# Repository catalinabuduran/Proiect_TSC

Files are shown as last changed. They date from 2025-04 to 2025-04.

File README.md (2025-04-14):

# OpenBook - Open Source e-Book Reader

## Functionalitate hardware

Dispozitivul OpenBook integreaza o serie de module si componente menite sa ofere o experienta completa pentru citirea cartilor in format digital, precum si extinderea functiilor prin senzori si periferice externe. Hardware-ul este compus din mai multe blocuri functionale, fiecare avand rolul. Am integrat atat componente de interfata (buton, ecran), cat si senzori, circuite de alimentare si protectie.

### Componente principale:

## Dispozitivul este compus dintr-un set de componente atent alese pentru a oferi un echilibru perfect intre performanta, consum redus de energie si modularitate. ##
|  Componenta | Descriere |
|---|---|
|ESP32-C6-WROOM-1-N8  | MCU principal cu WiFi 6, BLE 5.0, SPI, I2C, UART |
|E-paper Display | Afisaj ultra-low power, interfata SPI |
|SD Card | Stocare pentru fisiere e-book si configurari |
|NOR Flash 64MB  | Memorie suplimentara pentru firmware si date |
|RTC-DS3231SN | Ceas in timp real, exact si stabil |
| BME688 | Senzor de mediu complet: T, RH, presiune, VOC |
| MAX17048 | Masurare SoC baterie, tensiune, temperatura |
|MCP73831 | Incarcare LiPo simpla si eficienta |
|XC6220 LDO | Regulare 5V -> 3.3V cu zgomot scazut |
|USB-C | Alimentare + flash firmware + protectie ESD |
|Qwiic/Stemma QT | Extensie rapida pentru senzori I2C |

---

## Pinout ESP32-C6

Mai jos este un rezumat al pinilor folositi pe microcontroller, cu functiile si componenta asociata:

| GPIO  | Componenta | Functie |
|---|---|---|
| EN | Buton Reset | Reset hardware |
| IO0 | RTC | INT_RTC (interupt RTC) |
| IO1 | RTC | 32KHz output |
| IO2 | SD Card | MISO |
| IO3 | E-paper Display | EPD_BUSY |
| IO4 | SD Card | SS_SD (chip select) |
| IO5 | E-paper Display | EPD_DC |
| IO6 | SPI Shared | SCK |
| IO7 | SPI Shared | MOSI |
| IO8 | GPIO | Utilizare generica |
| IO9 | Boot Button | Mod programare |
| IO10 | E-paper Display | EPD_CS |
| IO11 | NOR Flash | FLASH_CS |
| IO12 | USB Interface | USB_D- |
| IO13 | USB Interface | USB_D+ |
| IO15 | Buton Change | Detectare schimbare |
| IO16 | UART | TX (debug serial) |
| IO17 | UART | RX (debug serial) |
| IO18 | RTC | RTC_RST |
| IO19 | MAX17048 | I2C_PW (alimentare I2C) |
| IO20 | E-paper Display | EPD_3V3_C (power control) |
| IO21 | I2C Shared | SDA |
| IO22 | I2C Shared | SCL |
| IO23 | E-paper Display | EPD_RST |

---

## Arhitectura si comunicatii

- **SPI Bus** este partajat intre: SD Card, E-paper Display, NOR Flash
- **I2C Bus** este partajat intre: RTC, BME688, MAX17048, Qwiic port
- **UART** este utilizat pentru debugging (TX/RX)
- **USB-C** foloseste GPIO dedicate pentru DP/DM si incarcare

---
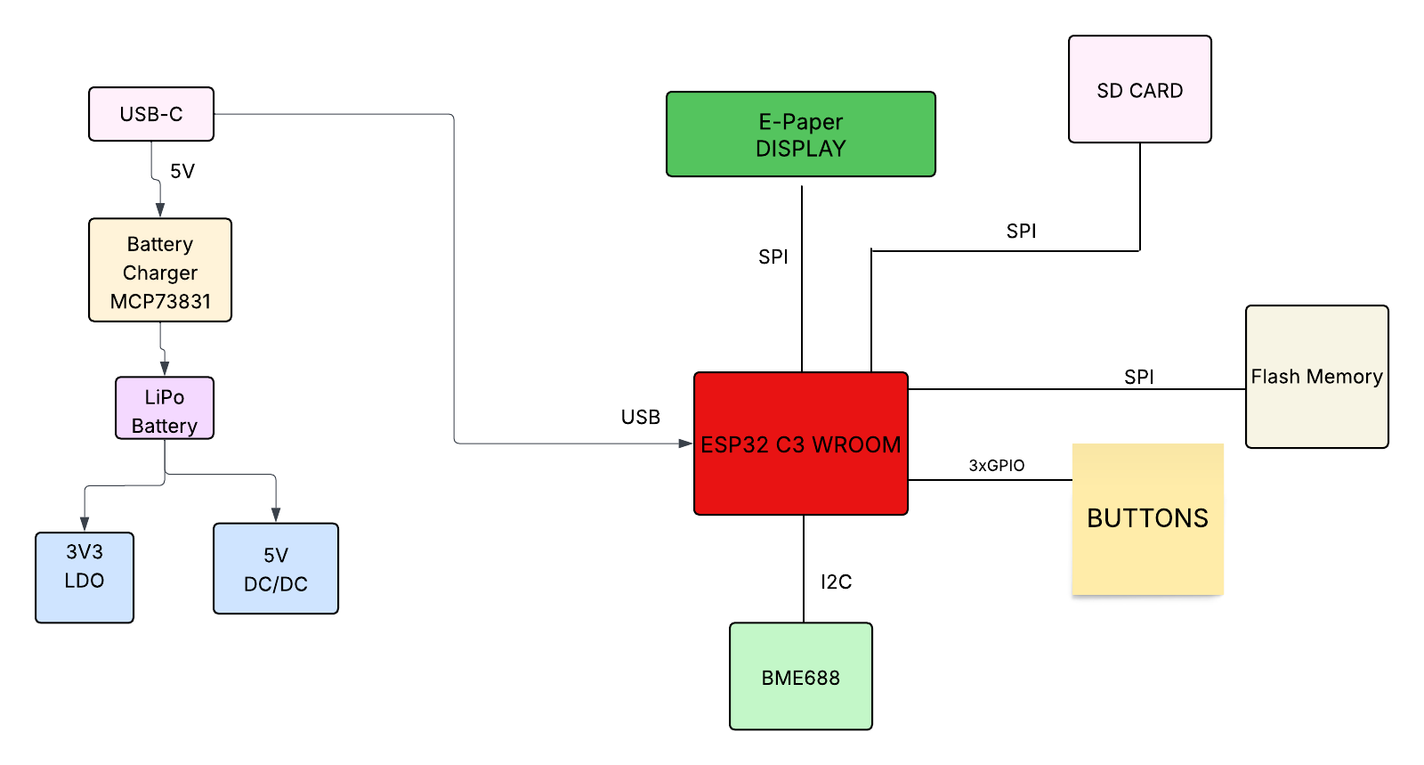
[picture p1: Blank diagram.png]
Diagrama BLOC


# BOM TSC - Lista de componente

| Nr. piesa | Nume piesa | Site | Datasheet |
| --- | --- | --- | --- |
| 1 | BOOT_BUTON | https://www.snapeda.com/parts/EVQP7L01P/Panasonic%20Electronic%20Components/view-part/?welcome=home | https://www.snapeda.com/parts/EVQP7L01P/Panasonic/datasheet/ |
| 2 | C1, C1_BAT, C1_BAT2, C2,C2_BAT,C3,C4,C4_USB, C5, C5_USB, C6, C7, C8, C9,C10 | https://componentsearchengine.com/part-view/CC0402MRX5R5BB106/YAGEO | https://componentsearchengine.com/Datasheets/2/CC0402MRX5R5BB106.pdf |
| 3 | C10_SUPERCAR | https://industry.panasonic.com/global/en/products/control/switch/light-touch/number/evqpuj02k | https://industry.panasonic.com/global/en/downloads?tab=catalog&small_g_cd=203&part_no=EVQPUJ02K |
| 4 | CHANGE_BUTTON | https://www.snapeda.com/parts/EVQP7L01P/Panasonic%20Electronic%20Components/view-part/?welcome=home | https://www.snapeda.com/parts/EVQP7L01P/Panasonic/datasheet/ |
| 5 | C_DELAY | https://componentsearchengine.com/part-view/CC0402MRX5R5BB106/YAGEO | https://componentsearchengine.com/Datasheets/2/CC0402MRX5R5BB106.pdf |
| 6 | D1 | https://www.snapeda.com/parts/USBLC6-2SC6Y/STMicroelectronics/view-part/?ref=eda | https://www.snapeda.com/parts/USBLC6-2SC6Y/STMicroelectronics/view-part/?ref=eda |
| 7 | EPD_C1,EPD_C2, EPD_C3, EPD_C4, EPD_C5,EPD_C6,EPD_C7,EPD_C8,EPD_C9,EPD_C10,EPD_C11,EPD_C12 | https://componentsearchengine.com/part-view/CC0402MRX5R5BB106/YAGEO | https://componentsearchengine.com/Datasheets/2/CC0402MRX5R5BB106.pdf |
| 8 | IC1 | https://componentsearchengine.com/part-view/BD5229G-TR/ROHM%20Semiconductor | https://datasheet.datasheetarchive.com/originals/distributors/Datasheets_SAMA/f2b9741ef86007909f138d561a359946.pdf |
| 9 | IC4 | https://componentsearchengine.com/part-view/XC6220A331MR-G/Torex | https://product.torexsemi.com/system/files/series/xc6220.pdf |
| 10 | J1 | https://componentsearchengine.com/part-view/FH34SRJ-24S-0.5SH(99)/Hirose | https://www.hirose.com/en/product/document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 |
| 11 | J2 | https://componentsearchengine.com/part-view/USB4110-GF-A/GCT%20(GLOBAL%20CONNECTOR%20TECHNOLOGY) | https://gct.co/files/drawings/usb4110.pdf |
| 12 | J3,J4 | https://www.snapeda.com/parts/PRT-14417/SparkFun/view-part/ | https://www.snapeda.com/parts/PRT-14417/SparkFun%20Electronics/datasheet/ |
| 13 | MCP73831 | https://ro.mouser.com/ProductDetail/Microchip-Technology/MCP73831T-2ACI-OT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 | https://ro.mouser.com/datasheet/2/268/MCP73831_Family_Data_Sheet_DS20001984H-3441711.pdf |
| 14 | L1 | https://ro.mouser.com/ProductDetail/Wurth-Elektronik/744043680?qs=PGXP4M47uW6VkZq%252BkzjrHA%3D%3D | https://www.we-online.com/components/products/datasheet/744043680.pdf |
| 15 | PFMF.050.1 | https://ro.mouser.com/ProductDetail/EPCOS-TDK/B72520T0350K062?qs=dEfas%2FXlABIszF52uu7vrg%3D%3D | https://www.tdk-electronics.tdk.com/inf/75/db/CTVS_14/Surge_protection_series.pdf |
| 16 | Q1,Q2 | https://componentsearchengine.com/part-view/DMG2305UX-7/Diodes%20Incorporated | https://www.diodes.com//assets/Datasheets/DMG2305UX.pdf |
| 17 | Q3 | https://componentsearchengine.com/part-view/SI1308EDL-T1-GE3/Vishay | https://componentsearchengine.com/part-view/SI1308EDL-T1-GE3/Vishay |
| 18 | Rezistente | https://componentsearchengine.com/part-view/R0402%201%25%20100%20K%20(RC0402FR-07100KL)/YAGEO | https://www.yageo.com/upload/media/product/products/datasheet/rchip/PYu-RC_Group_51_RoHS_L_12.pdf |
| 19 | RESET_BUTTON | https://www.snapeda.com/parts/EVQP7L01P/Panasonic%20Electronic%20Components/view-part/?welcome=home | https://www.snapeda.com/parts/EVQP7L01P/Panasonic/datasheet/ |
| 20 | R_BOOT | https://componentsearchengine.com/part-view/R0402%201%25%20100%20K%20(RC0402FR-07100KL)/YAGEO | https://www.yageo.com/upload/media/product/products/datasheet/rchip/PYu-RC_Group_51_RoHS_L_12.pdf |
| 21 | R_CAPACITOR | https://componentsearchengine.com/part-view/R0402%201%25%20100%20K%20(RC0402FR-07100KL)/YAGEO | https://www.yageo.com/upload/media/product/products/datasheet/rchip/PYu-RC_Group_51_RoHS_L_12.pdf |
| 22 | R_CHANGE | https://componentsearchengine.com/part-view/R0402%201%25%20100%20K%20(RC0402FR-07100KL)/YAGEO | https://www.yageo.com/upload/media/product/products/datasheet/rchip/PYu-RC_Group_51_RoHS_L_12.pdf |
| 23 | R_CL1 | https://componentsearchengine.com/part-view/R0402%201%25%20100%20K%20(RC0402FR-07100KL)/YAGEO | https://www.yageo.com/upload/media/product/products/datasheet/rchip/PYu-RC_Group_51_RoHS_L_12.pdf |
| 24 | R_RESET | https://componentsearchengine.com/part-view/R0402%201%25%20100%20K%20(RC0402FR-07100KL)/YAGEO | https://www.yageo.com/upload/media/product/products/datasheet/rchip/PYu-RC_Group_51_RoHS_L_12.pdf |
| 26 | SENSOR2 | https://www.snapeda.com/parts/BME680/Bosch/view-part/?welcome=home | https://www.snapeda.com/parts/BME680/Bosch%20Sensortec/datasheet/ |
| 27 | SJ1 | https://grabcad.com/library/solder-jumpers-1 | https://grabcad.com/library/solder-jumpers-1 |
| 28 | U1 | https://www.snapeda.com/parts/W25Q512JVEIQ/Winbond+Electronics/view-part/?ref=eda | https://www.snapeda.com/parts/W25Q512JVEIQ/Winbond+Electronics/view-part/?ref=eda |
| 29 | U2 | https://www.snapeda.com/parts/ESP32-C6-WROOM-1-N8/Espressif+Systems/view-part/?ref=eda | https://www.snapeda.com/parts/ESP32-C6-WROOM-1-N8/Espressif%20Systems/datasheet/ |
| 30 | U3 | https://www.snapeda.com/parts/DS3231SN%23/Analog+Devices/view-part/?ref=eda | https://www.snapeda.com/parts/DS3231SN%23/Analog%20Devices/datasheet/ |
| 31 | U4 | https://www.snapeda.com/parts/MAX17048G+T10/Analog+Devices/view-part/?ref=eda | https://www.snapeda.com/parts/MAX17048G+T10/Analog%20Devices/datasheet/ |
| 32 | TP-uri | Le-am desenat manual |  |

3D Design
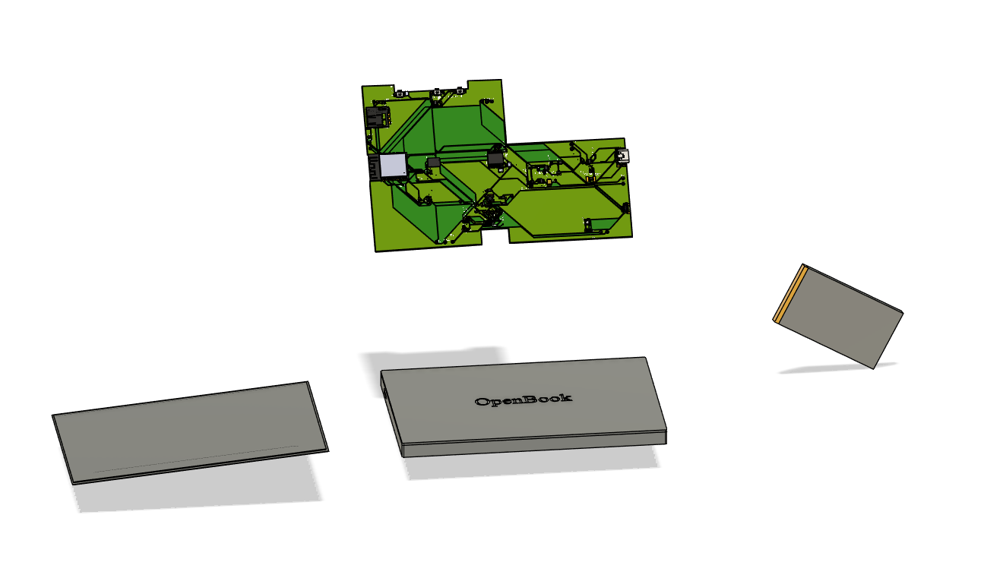
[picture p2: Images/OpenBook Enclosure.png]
OpenBook Enclosure


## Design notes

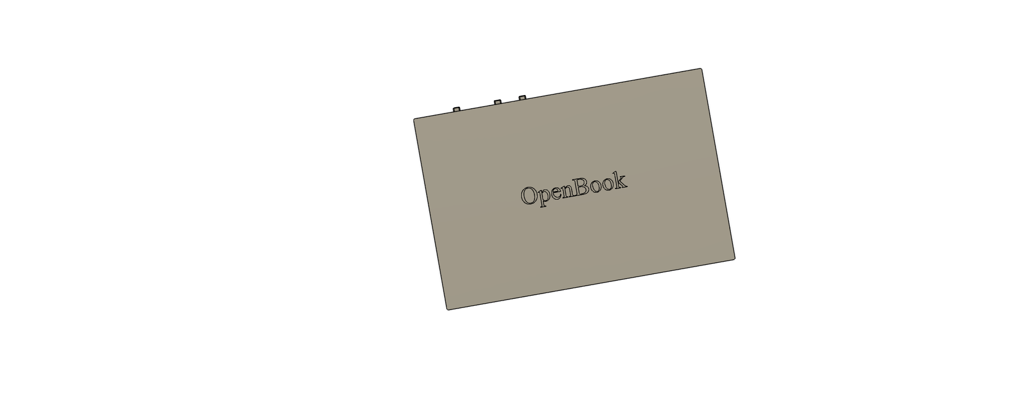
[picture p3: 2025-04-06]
Images/Carcasa.png

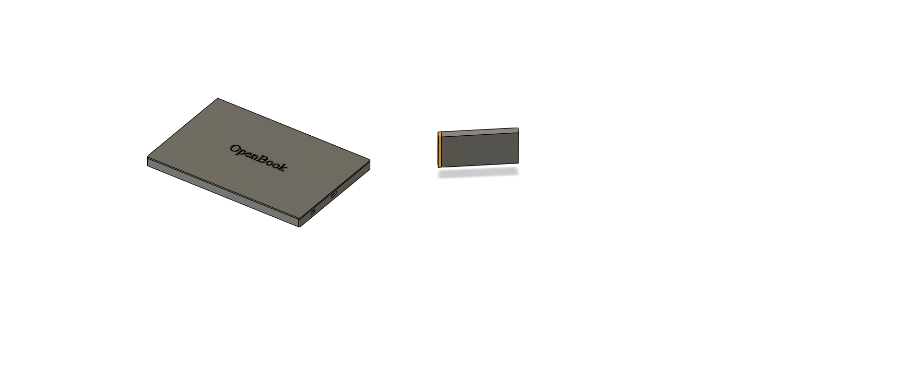
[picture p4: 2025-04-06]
Images/Baterie.png

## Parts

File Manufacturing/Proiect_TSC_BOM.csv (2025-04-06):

Qty | Value | Device | Package | Parts | Description | ARROW_PART_NUMBER | ARROW_PRICE-STOCK | AVAILABILITY | CATEGORY | CENTROID_NOT_SPECIFIED | CHECK_PRICES | COPYRIGHT | DATASHEET | DESCRIPTION | DIGIKEY_DESCRIPTION | DIGIKEY_PART_NUMBER | HEIGHT | LEAD_FREE | MANUFACTURER | MANUFACTURER_NAME | MANUFACTURER_PART_NUMBER | MF | MFR_NAME | MOUSER_PART_NUMBER | MOUSER_PRICE-STOCK | MOUSER_TESTING_PART_NUMBER | MOUSER_TESTING_PRICE-STOCK | MP | MPN | OPERATING_TEMPERATURE | PACKAGE | PACKAGE_SIZE | PACKAGE_TYPE | PART_STATUS | POPULARITY | PREFIX | PRICE | PROD_ID | PURCHASE-URL | ROHS | SERIES | SNAPEDA_LINK | SPICEMODEL | SPICEPREFIX | SUBCATEGORY | TEMPERATURE_COEFFICIENT | TEMPERATURE_RANGE_HIGH | TEMPERATURE_RANGE_LOW | THERMALLOSS | TOLERANCE | TP_SIGNAL_NAME | TYPE | VALUE
1 |  | ADAFRUIT_LEDCHIP-LED0603 | ADAFRUIT_CHIP-LED0603 | CHG_LED | LED
1 |  | ESP32_WROVER_EAGLE-LTSPICE_RR0402 | ESP32_WROVER_EAGLE-LTSPICE_R0402 | R_CAPACITOR | RESISTOR, European symbol |  |  |  |  |  |  |  |  |  |  |  |  |  |  |  |  |  |  |  |  |  |  |  |  |  |  |  |  |  |  |  |  |  |  |  |  |  | NONE | R
1 |  | SJ | SJ | SJ1 | SMD solder JUMPER |  |  |  |  |  |  |  |  |  |  |  |  |  |  |  |  |  |  |  |  |  |  |  |  |  |  |  |  |  | 3
1 | 0.1uF/50V | ESP32_WROVER_EAGLE-LTSPICE_CC0402 | ESP32_WROVER_EAGLE-LTSPICE_C0402 | EPD_C5 | CAPACITOR, European symbol |  |  |  |  |  |  |  |  |  |  |  |  |  |  |  |  |  |  |  |  |  |  |  |  |  |  |  |  |  |  |  |  |  |  |  |  |  | NONE | C
1 | 0.47 | R_CHIP-0402(1005-METRIC) | RESC1005X40 | R3 | Resistor Fixed - Generic |  |  |  | Resistors |  |  |  |  | Chip Resistor 1.05 X 0.54 X 0.40 mm body 0402(1005-METRIC) Package |  |  |  |  |  |  |  |  |  |  |  |  |  |  |  |  |  | 0402 | SMD
1 | 100K | ESP32_WROVER_EAGLE-LTSPICE_RR0402 | ESP32_WROVER_EAGLE-LTSPICE_R0402 | R1_PWRUSB | RESISTOR, European symbol |  |  |  |  |  |  |  |  |  |  |  |  |  |  |  |  |  |  |  |  |  |  |  |  |  |  |  |  |  |  |  |  |  |  |  |  |  | NONE | R
1 | 100K | R_CHIP-0402(1005-METRIC) | RESC1005X40 | R1 | Resistor Fixed - Generic |  |  |  | Resistors |  |  |  |  | Chip Resistor 1.05 X 0.54 X 0.40 mm body 0402(1005-METRIC) Package |  |  |  |  |  |  |  |  |  |  |  |  |  |  |  |  |  | 0402 | SMD
1 | 100k | R_CHIP-0402(1005-METRIC) | RESC1005X40 | R4 | Resistor Fixed - Generic |  |  |  | Resistors |  |  |  |  | Chip Resistor 1.05 X 0.54 X 0.40 mm body 0402(1005-METRIC) Package |  |  |  |  |  |  |  |  |  |  |  |  |  |  |  |  |  | 0402 | SMD
1 | 100nF | EAGLE-LTSPICE_CC0402 | EAGLE-LTSPICE_C0402 | C8 | CAPACITOR, European symbol |  |  |  |  |  |  |  |  |  |  |  |  |  |  |  |  |  |  |  |  |  |  |  |  |  |  |  |  |  |  |  |  |  |  |  |  |  | NONE | C
7 | 100nF | ESP32_WROVER_EAGLE-LTSPICE_CC0402 | ESP32_WROVER_EAGLE-LTSPICE_C0402 | C1, C2, C4_USB, C6, C9, C10, C_DELAY | CAPACITOR, European symbol |  |  |  |  |  |  |  |  |  |  |  |  |  |  |  |  |  |  |  |  |  |  |  |  |  |  |  |  |  |  |  |  |  |  |  |  |  | NONE | C
1 | 100uF TANT | RCL_CPOL-EUCT3528 | RCL_CT3528 | C3 | POLARIZED CAPACITOR, European symbol |  |  |  |  |  |  |  |  |  |  |  |  |  |  |  |  |  |  |  |  |  |  |  |  |  |  |  |  |  | 0 |  |  |  |  |  |  |  |  | C
14 | 10K | ESP32_WROVER_EAGLE-LTSPICE_RR0402 | ESP32_WROVER_EAGLE-LTSPICE_R0402 | R1_PINH, R1_PINH1, R2-PINH, R2-PINH1, R5, R6, R7, R8, R9, R10, R_BOOT, R_CHANGE, R_CL1, R_RESET | RESISTOR, European symbol |  |  |  |  |  |  |  |  |  |  |  |  |  |  |  |  |  |  |  |  |  |  |  |  |  |  |  |  |  |  |  |  |  |  |  |  |  | NONE | R
1 | 10uF | ESP32_WROVER_EAGLE-LTSPICE_CC0402 | ESP32_WROVER_EAGLE-LTSPICE_C0402 | C7 | CAPACITOR, European symbol |  |  |  |  |  |  |  |  |  |  |  |  |  |  |  |  |  |  |  |  |  |  |  |  |  |  |  |  |  |  |  |  |  |  |  |  |  | NONE | C
1 | 112A-TAAR-R03_ATTEND | 112A-TAAR-R03_ATTEND | 112ATAARR03ATTEND | J4 | Micro SD Card Socket, Push-Push Type, Top Mount, SMT, H=1.83mm, 10u |  |  |  |  |  |  |  |  | Micro SD Card Socket | Push-Push Type | Top Mount | SMT | H=1.83mm | 10u |  |  | 1.9mm |  |  | ATTEND | 112A-TAAR-R03 ATTEND
1 | 1uF | EAGLE-LTSPICE_CC0402 | EAGLE-LTSPICE_C0402 | C5 | CAPACITOR, European symbol |  |  |  |  |  |  |  |  |  |  |  |  |  |  |  |  |  |  |  |  |  |  |  |  |  |  |  |  |  |  |  |  |  |  |  |  |  | NONE | C
1 | 1uF/50F | ESP32_WROVER_EAGLE-LTSPICE_CC0402 | ESP32_WROVER_EAGLE-LTSPICE_C0402 | EPD_C12 | CAPACITOR, European symbol |  |  |  |  |  |  |  |  |  |  |  |  |  |  |  |  |  |  |  |  |  |  |  |  |  |  |  |  |  |  |  |  |  |  |  |  |  | NONE | C
8 | 1uF/50V | ESP32_WROVER_EAGLE-LTSPICE_CC0402 | ESP32_WROVER_EAGLE-LTSPICE_C0402 | EPD_C1, EPD_C2, EPD_C6, EPD_C7, EPD_C8, EPD_C9, EPD_C10, EPD_C11 | CAPACITOR, European symbol |  |  |  |  |  |  |  |  |  |  |  |  |  |  |  |  |  |  |  |  |  |  |  |  |  |  |  |  |  |  |  |  |  |  |  |  |  | NONE | C
1 | 2.2 | R_CHIP-0402(1005-METRIC) | RESC1005X40 | R2 | Resistor Fixed - Generic |  |  |  | Resistors |  |  |  |  | Chip Resistor 1.05 X 0.54 X 0.40 mm body 0402(1005-METRIC) Package |  |  |  |  |  |  |  |  |  |  |  |  |  |  |  |  |  | 0402 | SMD
1 | 200 | R_CHIP-0402(1005-METRIC) | RESC1005X40 | R1_BAT | Resistor Fixed - Generic |  |  |  | Resistors |  |  |  |  | Chip Resistor 1.05 X 0.54 X 0.40 mm body 0402(1005-METRIC) Package |  |  |  |  |  |  |  |  |  |  |  |  |  |  |  |  |  | 0402 | SMD
2 | 20V/4.2A/52m?/1.4W | ESP32_WROVER_SPARKFUN-DISCRETESEMI_MOSFET_PCH-DMG2305UX-7 | ESP32_WROVER_SPARKFUN-DISCRETESEMI_SOT23-3 | Q1, Q2 | P-channel MOSFETs |  |  |  |  |  |  |  |  |  |  |  |  |  |  |  |  |  |  |  |  |  |  |  |  |  |  |  |  |  |  |  |  | TRAN-14388 |  |  |  |  |  |  |  |  |  |  |  |  |  |  | 20V/4.2A/52m?/1.4W
1 | 2K | R_CHIP-0402(1005-METRIC) | RESC1005X40 | R2_BAT | Resistor Fixed - Generic |  |  |  | Resistors |  |  |  |  | Chip Resistor 1.05 X 0.54 X 0.40 mm body 0402(1005-METRIC) Package |  |  |  |  |  |  |  |  |  |  |  |  |  |  |  |  |  | 0402 | SMD
5 | 4.7uF | ESP32_WROVER_EAGLE-LTSPICE_CC0402 | ESP32_WROVER_EAGLE-LTSPICE_C0402 | C1_BAT, C1_BAT1, C1_BAT2, C2_BAT, C5_USB | CAPACITOR, European symbol |  |  |  |  |  |  |  |  |  |  |  |  |  |  |  |  |  |  |  |  |  |  |  |  |  |  |  |  |  |  |  |  |  |  |  |  |  | NONE | C
1 | 4.7uF/25V | ESP32_WROVER_EAGLE-LTSPICE_CC0402 | ESP32_WROVER_EAGLE-LTSPICE_C0402 | C4 | CAPACITOR, European symbol |  |  |  |  |  |  |  |  |  |  |  |  |  |  |  |  |  |  |  |  |  |  |  |  |  |  |  |  |  |  |  |  |  |  |  |  |  | NONE | C
2 | 5K1 | ESP32_WROVER_EAGLE-LTSPICE_RR0402 | ESP32_WROVER_EAGLE-LTSPICE_R0402 | R2-USB, R2-USB1 | RESISTOR, European symbol |  |  |  |  |  |  |  |  |  |  |  |  |  |  |  |  |  |  |  |  |  |  |  |  |  |  |  |  |  |  |  |  |  |  |  |  |  | NONE | R
1 | 68uH | 744043680IND_4828-WE-TPC_WRE | IND_4828-WE-TPC_WRE | L1 |  |  |  |  |  |  |  | Copyright (C) 2024 Ultra Librarian. All rights reserved. |  |  |  |  |  |  |  |  | 744043680 |  | Wurth Electronics
1 | BD5229G-TR | BD5229G-TR | SOT95P280X125-5N | IC1 | Voltage Detector with Adjustable Delay Time: CMOS processes are utilized to develop high precision, low current consumption CMOS reset ICs that allow arbitrary setting of the delay time. The extensive lineup includes both Nch Open Drain and CMOS output types in a wide range of detection voltages (from 2.3V to 6.0V, in 0.1V steps), enabling selection of the ideal solution based on customer requirements. In addition, the entire series is of course both lead-free and RoHS-compliant. |  |  |  |  |  |  |  |  | Voltage Detector with Adjustable Delay Time: CMOS processes are utilized to develop high precision | low current consumption CMOS reset ICs that allow arbitrary setting of the delay time. The extensive lineup includes both Nch Open Drain and CMOS output types in a wide range of detection voltages (from 2.3V to 6.0V | in 0.1V steps) | enabling selection of the ideal solution based on customer requirements. In addition | the entire series is of course both lead-free and RoHS-compliant. |  |  | 1.25mm |  |  | ROHM Semiconductor | BD5229G-TR |  |  | 755-BD5229G-TR | https://www.mouser.co.uk/ProductDetail/ROHM-Semiconductor/BD5229G-TR?qs=4kLU8WoGk0vvnhrrYwdszw%3D%3D
3 | BUTTON_CUSYOMV1 | BUTTON_CUSYOMV1 | MYBUTTON | BOOT_BUTTON, CHANGE_BUTTON, RESET_BUTTON
1 | CPH3225A | EAGLE-LTSPICE_CC0402 | EAGLE-LTSPICE_C0402 | C10_SUPERCAP | CAPACITOR, European symbol |  |  |  |  |  |  |  |  |  |  |  |  |  |  |  |  |  |  |  |  |  |  |  |  |  |  |  |  |  |  |  |  |  |  |  |  |  | NONE | C
1 | DS3231SN# | DS3231SN# | SOIC127P1032X265-16N | U3 | Real Time Clock Serial 16-Pin SOIC W T/R Check availability |  |  | In Stock |  |  | https://www.snapeda.com/parts/DS3231SN%23/Analog+Devices/view-part/?ref=eda |  |  | Extremely Accurate I2C-Integrated RTC/TCXO/Crystal |  |  |  |  |  |  |  | Analog Devices |  |  |  |  |  | DS3231SN# |  |  | SOIC-16 Maxim |  |  |  |  |  | None |  | https://www.snapeda.com/api/url_track_click_mouser/?unipart_id=99048&manufacturer=Analog Devices&part_name=DS3231SN#&search_term=None |  |  | https://www.snapeda.com/parts/DS3231SN%23/Analog+Devices/view-part/?ref=snap
1 | ESP32-C6-WROOM-1-N8 | ESP32-C6-WROOM-1-N8 | XCVR_ESP32-C6-WROOM-1-N8 | U2 | Check availability |  |  | In Stock |  |  | https://www.snapeda.com/parts/ESP32-C6-WROOM-1-N8/Espressif+Systems/view-part/?ref=eda |  |  | Multiprotocol Modules ESP32-C6 module | Wi-Fi 6 in 2.4 GHz band | Bluetooth 5 | Zigbee 3.0 and Thread. ESP34-WROOM Compatible - ENGINEERING SAMPLE |  |  |  |  |  |  |  | Espressif Systems |  |  |  |  |  | ESP32-C6-WROOM-1-N8 |  |  | None |  |  |  |  |  | None |  |  |  |  | https://www.snapeda.com/parts/ESP32-C6-WROOM-1-N8/Espressif+Systems/view-part/?ref=snap
1 | ESP32C6_VARISTORCN1812 | ESP32C6_VARISTORCN1812 | ESP32C6_VARISTOR_CT/CN1812 | PFMF.050.1 | VARISTOR |  |  |  |  |  |  |  |  |  |  |  |  |  |  |  |  |  |  |  |  |  |  |  |  |  |  |  |  |  | 0
2 | ESP32_WROVER_AVX---SD0805S020S1R0_AVX_SD0805S020S1R0_0_0AVX_SD0805S020S1R0_0_0 | ESP32_WROVER_AVX---SD0805S020S1R0_AVX_SD0805S020S1R0_0_0AVX_SD0805S020S1R0_0_0 | ESP32_WROVER_AVX---SD0805S020S1R0_AVX_SD0805S020S1R0_0 | D2, D7 | Schottky Barrier Rectifier Diode |  |  |  |  | No |  |  | http://datasheets.avx.com/schottky.pdf |  | DIODE SCHOTTKY 20V 1A 0805 | 478-7800-1-ND |  | yes |  |  |  | AVX |  | 581-SD0805S020S1R0 |  |  |  |  |  |  | 0805 (2012 metric) |  |  |  |  | D |  |  |  | yes |  |  |  |  |  |  | +125°C | -55°C
1 | ESP32_WROVER_BME680_BME680 | ESP32_WROVER_BME680_BME680 | ESP32_WROVER_BME680_PSON80P300X300X100-8N | SENSOR2 | Integrated Environmental Unit |  |  | Unavailable |  |  |  |  |  | Integrated Environmental Unit |  |  |  |  |  |  |  | Bosch Sensortec |  |  |  |  |  | BME680 |  |  | LGA-8 Bosch Tools |  |  |  |  |  | None
1 | ESP32_WROVER_SPARKFUN-IC-POWER_MCP73831 | ESP32_WROVER_SPARKFUN-IC-POWER_MCP73831 | ESP32_WROVER_SPARKFUN-IC-POWER_SOT23-5 | U5 | MCP73831T Li-Ion, Li-Pol Controller |  |  |  |  |  |  |  |  |  |  |  |  |  |  |  |  |  |  |  |  |  |  |  |  |  |  |  |  |  |  |  |  | IC-09995
1 | FH34SRJ-24S-0.5SH_99_ | FH34SRJ-24S-0.5SH_99_ | FH34SRJ24S05SH99 | J1 | (0.50mm) Surface Mount, Right Angle |  |  |  |  |  |  |  |  | 24 Position FFC | FPC Connector Contacts | (0.50mm) Surface Mount | Right Angle |  |  | 1.1mm |  |  | Hirose | FH34SRJ-24S-0.5SH(99) |  |  | 798-FH34SRJ24S05SH99 | https://www.mouser.co.uk/ProductDetail/Hirose-Connector/FH34SRJ-24S-0.5SH99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
1 | MAX17048G+T10 | MAX17048G+T10 | SON50P200X200X80-9N | U4 | Check availability |  |  | In Stock |  |  | https://www.snapeda.com/parts/MAX17048G+T10/Analog+Devices/view-part/?ref=eda |  |  | 3µA 1-Cell/2-Cell Fuel Gauge with ModelGauge |  |  |  |  |  |  |  | Analog Devices |  |  |  |  |  | MAX17048G+T10 |  |  | TDFN-8 Maxim |  |  |  |  |  | None |  | https://www.snapeda.com/api/url_track_click_mouser/?unipart_id=329239&manufacturer=Analog Devices&part_name=MAX17048G+T10&search_term=None |  |  | https://www.snapeda.com/parts/MAX17048G+T10/Analog+Devices/view-part/?ref=snap
3 | MBR0530 | MBR0530 | SOD3716X135N | D3, D4, D5 | ON SEMICONDUCTOR - MBR0530 - DIODE, SCHOTTKY, 0.5A, 30V, SOD-123 |  |  | In Stock |  |  | https://www.snapeda.com/parts/MBR0530/Onsemi/view-part/?ref=eda |  |  | Diode Schottky 30 V 500mA Surface Mount SOD-123 |  |  |  |  |  |  |  | ON Semiconductor |  |  |  |  |  | MBR0530 |  |  | SOD-123-2 ON Semiconductor |  |  |  |  |  | None |  | https://www.snapeda.com/api/url_track_click_mouser/?unipart_id=179458&manufacturer=ON Semiconductor&part_name=MBR0530&search_term=None |  |  | https://www.snapeda.com/parts/MBR0530/Onsemi/view-part/?ref=snap
6 | PGB1010603MR | PGB1010603MR | DIOC1608X36N | D6, D8, D9, D10, D11, D12 | Check availability |  |  | In Stock |  |  | https://www.snapeda.com/parts/PGB1010603MR/Littelfuse/view-part/?ref=eda |  |  | 150V (Typ) Clamp - Ipp Tvs Diode Surface Mount 0603 (1608 Metric) |  |  |  |  |  |  |  | Littelfuse Inc. |  |  |  |  |  | PGB1010603MR |  |  | 0603 Littelfuse Inc. |  |  |  |  |  | None |  | https://www.snapeda.com/api/url_track_click_mouser/?unipart_id=5659453&manufacturer=Littelfuse Inc.&part_name=PGB1010603MR&search_term=None |  |  | https://www.snapeda.com/parts/PGB1010603MR/Littelfuse/view-part/?ref=snap
1 | QWIIC_RIGHT_ANGLE | QWIIC_CONNECTORJS-1MM | JST04_1MM_RA | J3 | SparkFun I2C Standard Qwiic Connector |  |  |  |  |  |  |  |  |  |  |  |  |  |  |  |  |  |  |  |  |  |  |  |  |  |  |  |  |  |  |  |  | CONN-13694 |  |  |  |  |  |  |  |  |  |  |  |  |  |  | QWIIC_RIGHT_ANGLE
1 | SAMACSYS_PARTS_USB4110-GF-A | SAMACSYS_PARTS_USB4110-GF-A | SAMACSYS_PARTS_USB4110GFA | J2 | CONN USB 2.0 TYPE-C R/A SMT |  |  |  |  |  |  |  |  | CONN USB 2.0 TYPE-C R/A SMT |  |  | 3.26mm |  |  | GCT (GLOBAL CONNECTOR TECHNOLOGY) | USB4110-GF-A |  |  | 640-USB4110-GF-A | https://www.mouser.co.uk/ProductDetail/GCT/USB4110-GF-A?qs=KUoIvG%2F9IlYiZvIXQjyJeA%3D%3D
1 | SI1308EDL-T1-GE3 | SI1308EDL-T1-GE3 | SOT65P210X110-3N | Q3 | MOSFET N-Ch 30V 1.5A TrenchFET SC70 Vishay Si1308EDL-T1-GE3 N-channel MOSFET Transistor, 1.5 A, 30 V, 3-Pin SC-70 |  |  | In Stock |  |  | https://www.snapeda.com/parts/SI1308EDL-T1-GE3/Vishay+Siliconix/view-part/?ref=eda |  |  | Si1308EDL-T1-GE3 N-channel MOSFET Transistor | 1.5 A | 30 V | 3-Pin SC-70 | Siliconix / Vishay SI1308EDL-T1-GE3 |  |  |  |  |  |  |  | Vishay Siliconix |  |  |  |  |  | SI1308EDL-T1-GE3 |  |  | SOT-323 Vishay Semiconductor |  |  |  |  |  | None |  | https://www.snapeda.com/api/url_track_click_mouser/?unipart_id=274603&manufacturer=Vishay Siliconix&part_name=SI1308EDL-T1-GE3&search_term=None |  |  | https://www.snapeda.com/parts/SI1308EDL-T1-GE3/Vishay+Siliconix/view-part/?ref=snap
17 | TPTP20R | TPTP20R | TP20R | TP1, TP2, TP3, TP4, TP5, TP6, TP7, TP8, TP9, TP10, TP11, TP12, TP13, TP14, TP15, TP16, TP17 | Test pad |  |  |  |  |  |  |  |  |  |  |  |  |  |  |  |  |  |  |  |  |  |  |  |  |  |  |  |  |  | 2
1 | USBLC6-2SC6Y | USBLC6-2SC6Y | SOT95P280X145-6N | D1 | Low Cap. ESD Protection Auto SOT-23-6 STMicroelectronics USBLC6-2SC6Y, Dual Uni-Directional TVS Diode Array, 6-Pin SOT-23 |  |  | In Stock |  |  | https://www.snapeda.com/parts/USBLC6-2SC6Y/STMicroelectronics/view-part/?ref=eda |  |  | 17V Clamp 5A (8/20µs) Ipp Tvs Diode Surface Mount SOT-23-6 |  |  |  |  |  |  |  | STMicroelectronics |  |  |  |  |  | USBLC6-2SC6Y |  |  | SOT-23-6 STMicroelectronics |  |  |  |  |  | None |  |  |  |  | https://www.snapeda.com/parts/USBLC6-2SC6Y/STMicroelectronics/view-part/?ref=snap
1 | W25Q512JVEIQ | W25Q512JVEIQ | SON127P600X800X80-9N | U1 | Check availability |  |  | In Stock |  |  | https://www.snapeda.com/parts/W25Q512JVEIQ/Winbond+Electronics/view-part/?ref=eda |  |  | FLASH - NOR Memory IC 512Mb (64M x 8) SPI - Quad I/O 133 MHz 8-WSON (8x6) |  |  |  |  |  |  |  | Winbond Electronics |  |  |  |  |  | W25Q512JVEIQ |  |  | Package |  |  |  |  |  | None |  |  |  |  | https://www.snapeda.com/parts/W25Q512JVEIQ/Winbond+Electronics/view-part/?ref=snap
1 | XC6220A331MR-G | XC6220A331MR-G | SOT95P280X120-5N | IC4 | LDO Voltage Regulators |  |  |  |  |  |  |  |  | LDO Voltage Regulators |  |  | 1.2mm |  |  | Torex | XC6220A331MR-G |  |  | 865-XC6220A331MR-G | https://www.mouser.co.uk/ProductDetail/Torex-Semiconductor/XC6220A331MR-G?qs=AsjdqWjXhJ8ZSWznL1J0gg%3D%3D

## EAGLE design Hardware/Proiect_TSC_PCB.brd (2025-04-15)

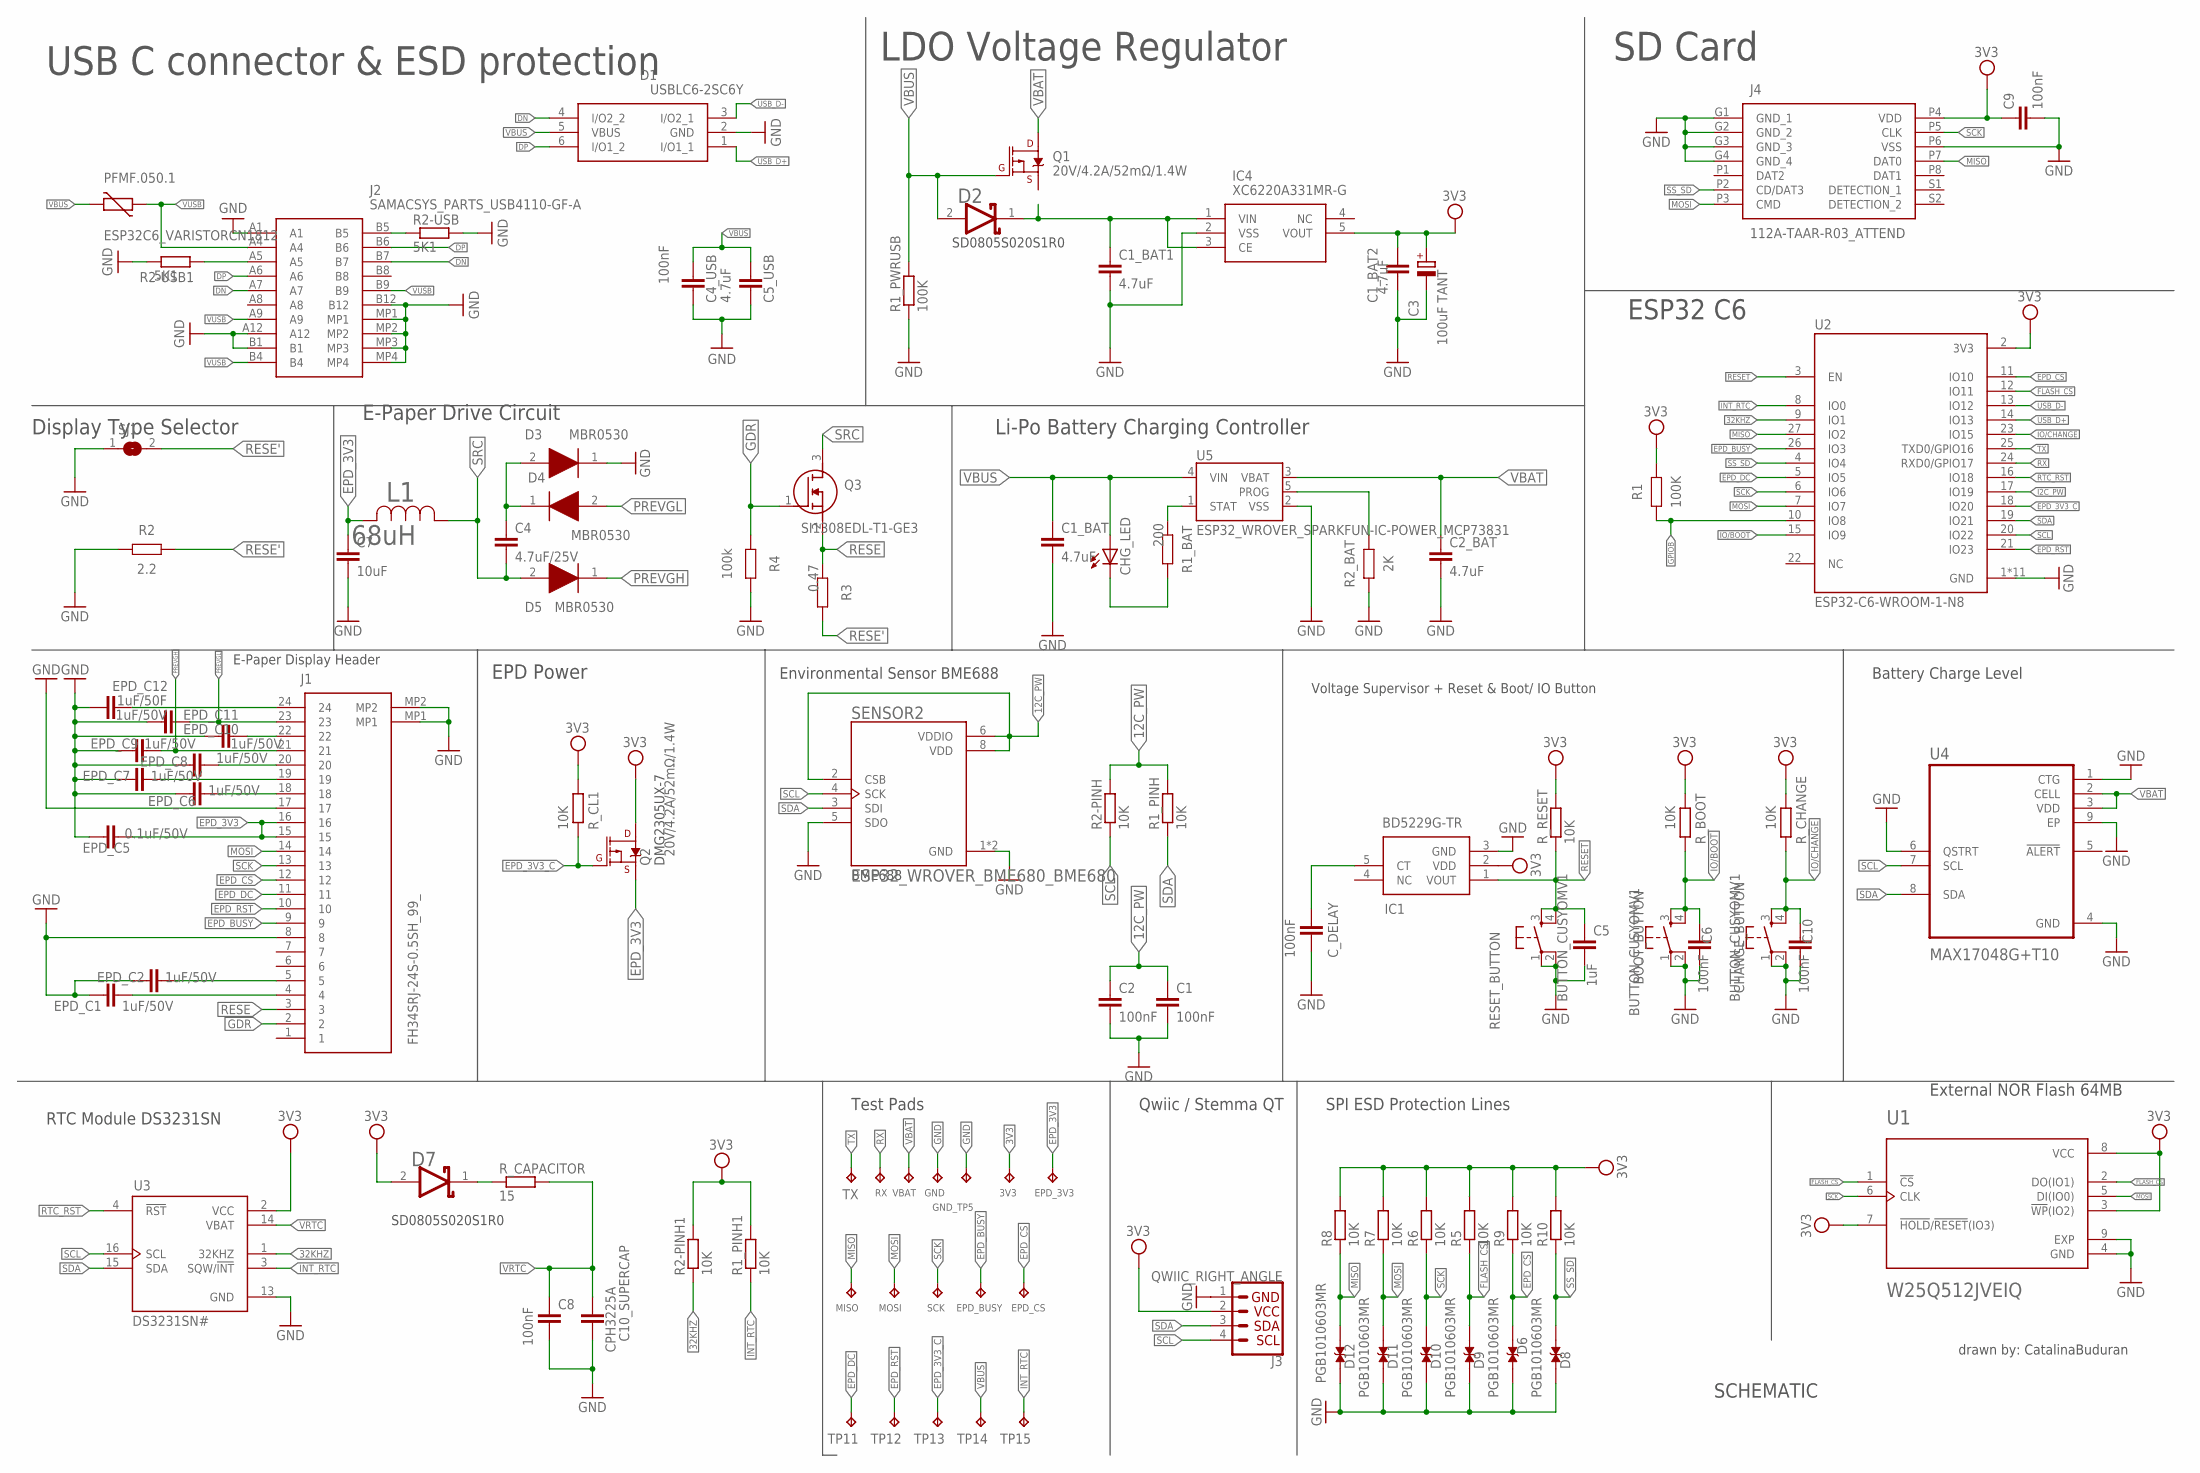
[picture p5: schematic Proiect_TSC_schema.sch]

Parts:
3V3: TPTP20R; TP20R
BOOT_BUTTON: BUTTON_CUSYOMV1; MYBUTTON
C1, C2, C4_USB, C6, C9, C10: 100nF; ESP32_WROVER_EAGLE-LTSPICE_C0402
C1_BAT, C1_BAT1, C1_BAT2, C2_BAT, C5_USB: 4.7uF; ESP32_WROVER_EAGLE-LTSPICE_C0402
C3: 100uF TANT; RCL_CT3528
C4: 4.7uF/25V; ESP32_WROVER_EAGLE-LTSPICE_C0402
C5: 1uF; EAGLE-LTSPICE_C0402
C7: 10uF; ESP32_WROVER_EAGLE-LTSPICE_C0402
C8: 100nF; EAGLE-LTSPICE_C0402
C10_SUPERCAP: CPH3225A; EAGLE-LTSPICE_C0402
CHANGE_BUTTON: BUTTON_CUSYOMV1; MYBUTTON
CHG_LED: ADAFRUIT_LEDCHIP-LED0603; ADAFRUIT_CHIP-LED0603
C_DELAY: 100nF; ESP32_WROVER_EAGLE-LTSPICE_C0402
D1: USBLC6-2SC6Y; SOT95P280X145-6N
D2, D7: ESP32_WROVER_AVX---SD0805S020S1R0_AVX_SD0805S020S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; ESP32_WROVER_AVX---SD0805S020S1R0_AVX_SD0805S020S1R0_0
D3, D4, D5: MBR0530; SOD3716X135N
D6, D8, D9, D10, D11, D12: PGB1010603MR; DIOC1608X36N
EPD_3V3: TPTP20R; TP20R
EPD_BUSY: TPTP20R; TP20R
EPD_C1, EPD_C2, EPD_C6, EPD_C7, EPD_C8, EPD_C9, EPD_C10, EPD_C11: 1uF/50V; ESP32_WROVER_EAGLE-LTSPICE_C0402
EPD_C5: 0.1uF/50V; ESP32_WROVER_EAGLE-LTSPICE_C0402
EPD_C12: 1uF/50F; ESP32_WROVER_EAGLE-LTSPICE_C0402
EPD_CS: TPTP20R; TP20R
GND: TPTP20R; TP20R
GND_TP5: TPTP20R; TP20R
IC1: BD5229G-TR; SOT95P280X125-5N
IC4: XC6220A331MR-G; SOT95P280X120-5N
J1: FH34SRJ-24S-0.5SH_99_; FH34SRJ24S05SH99
J2: SAMACSYS_PARTS_USB4110-GF-A; SAMACSYS_PARTS_USB4110GFA
J3: QWIIC_RIGHT_ANGLE; JST04_1MM_RA
J4: 112A-TAAR-R03_ATTEND; 112ATAARR03ATTEND
L1: 68uH; IND_4828-WE-TPC_WRE
MISO: TPTP20R; TP20R
MOSI: TPTP20R; TP20R
PFMF.050.1: ESP32C6_VARISTORCN1812; ESP32C6_VARISTOR_CT/CN1812
Q1, Q2: 20V/4.2A/52mΩ/1.4W; ESP32_WROVER_SPARKFUN-DISCRETESEMI_SOT23-3
Q3: SI1308EDL-T1-GE3; SOT65P210X110-3N
R1: 100K; RESC1005X40
R1_BAT: 200; RESC1005X40
R1_PINH, R1_PINH1, R2-PINH, R2-PINH1, R5, R6, R7, R8, R9, R10: 10K; ESP32_WROVER_EAGLE-LTSPICE_R0402
R1_PWRUSB: 100K; ESP32_WROVER_EAGLE-LTSPICE_R0402
R2: 2.2; RESC1005X40
R2-USB, R2-USB1: 5K1; ESP32_WROVER_EAGLE-LTSPICE_R0402
R2_BAT: 2K; RESC1005X40
R3: 0.47; RESC1005X40
R4: 100k; RESC1005X40
RESET_BUTTON: BUTTON_CUSYOMV1; MYBUTTON
RX: TPTP20R; TP20R
R_BOOT: 10K; ESP32_WROVER_EAGLE-LTSPICE_R0402
R_CAPACITOR: 15; ESP32_WROVER_EAGLE-LTSPICE_R0402
R_CHANGE: 10K; ESP32_WROVER_EAGLE-LTSPICE_R0402
R_CL1: 10K; ESP32_WROVER_EAGLE-LTSPICE_R0402
R_RESET: 10K; ESP32_WROVER_EAGLE-LTSPICE_R0402
SCK: TPTP20R; TP20R
SENSOR2: ESP32_WROVER_BME680_BME680; ESP32_WROVER_BME680_PSON80P300X300X100-8N
SJ1: SJ
TP11, TP12, TP13, TP14, TP15: TPTP20R; TP20R
TX: TPTP20R; TP20R
U1: W25Q512JVEIQ; SON127P600X800X80-9N
U2: ESP32-C6-WROOM-1-N8; XCVR_ESP32-C6-WROOM-1-N8
U3: DS3231SN#; SOIC127P1032X265-16N
U4: MAX17048G+T10; SON50P200X200X80-9N
U5: ESP32_WROVER_SPARKFUN-IC-POWER_MCP73831; ESP32_WROVER_SPARKFUN-IC-POWER_SOT23-5
VBAT: TPTP20R; TP20R

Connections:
3V3: 3V3.TP, C1_BAT2.1, C3.+, C9.1, D7.2 (ANODE), IC1.2 (VDD), IC4.5 (VOUT), J3.2, J4.P4 (VDD), Q2.3 (D), R1.2, R1_PINH1.2, R2-PINH1.2, R5.2, R6.2, R7.2, R8.2, R9.2, R10.2, R_BOOT.2, R_CHANGE.2, R_CL1.2, R_RESET.2, U1.3 (!WP!(IO2)), U1.7 (!HOLD!/!RESET!(IO3)), U1.8 (VCC), U2.2 (3V3), U3.2 (VCC)
12C_PW: C1.1, C2.1, R1_PINH.2, R2-PINH.2, SENSOR2.2 (CSB), SENSOR2.6 (VDDIO), SENSOR2.8 (VDD)
32KHZ: R2-PINH1.1, U2.9 (IO1), U3.1 (32KHZ)
DN: D1.4 (I/O2_2), J2.A7, J2.B7
DP: D1.6 (I/O1_2), J2.A6, J2.B6
EPD_3V3: C7.1, EPD_3V3.TP, EPD_C5.2, J1.15, J1.16, L1.2, Q2.2 (S)
EPD_3V3_C: Q2.1 (G), R_CL1.1, TP13.TP, U2.18 (IO20)
EPD_BUSY: EPD_BUSY.TP, J1.9, U2.26 (IO3)
EPD_CS: D6.2, EPD_CS.TP, J1.12, R9.1, U2.11 (IO10)
EPD_DC: J1.11, TP11.TP, U2.5 (IO5)
EPD_RST: J1.10, TP12.TP, U2.21 (IO23)
FLASH_CS: D9.2, R5.1, U1.1 (!CS), U2.12 (IO11)
GDR: J1.2, Q3.1 (G), R4.2
GND: BOOT_BUTTON.1, BOOT_BUTTON.2, C1.2, C1_BAT.2, C1_BAT1.2, C1_BAT2.2, C2.2, C2_BAT.2, C3.-, C4_USB.2, C5.2, C5_USB.2, C6.2, C7.2, C8.2, C9.2, C10.2, C10_SUPERCAP.2, CHANGE_BUTTON.1, CHANGE_BUTTON.2, C_DELAY.2, D1.2 (GND), D3.1 (K), D6.1, D8.1, D9.1, D10.1, D11.1, D12.1, EPD_C1.1, EPD_C2.1, EPD_C5.1, EPD_C6.1, EPD_C7.1, EPD_C8.1, EPD_C9.1, EPD_C10.1, EPD_C11.1, EPD_C12.1, GND.TP, GND_TP5.TP, IC1.3 (GND), IC4.2 (VSS), J1.8, J1.17, J1.MP1, J1.MP2, J2.A1, J2.A12, J2.B1, J2.B12, J2.MP1, J2.MP2, J2.MP3, J2.MP4, J3.1, J4.G1 (GND_1), J4.G2 (GND_2), J4.G3 (GND_3), J4.G4 (GND_4), J4.P6 (VSS), R1_PWRUSB.1, R2.1, R2-USB.2, R2-USB1.1, R2_BAT.1, R4.1, RESET_BUTTON.1, RESET_BUTTON.2, SENSOR2.1 (GND), SENSOR2.5 (SDO), SENSOR2.7 (GND), SJ1.1, U1.4 (GND), U1.9 (EXP), U2.1 (GND), U2.28 (GND), U2.29_1 (GND), U2.29_2 (GND), U2.29_3 (GND), U2.29_4 (GND), U2.29_5 (GND), U2.29_6 (GND), U2.29_7 (GND), U2.29_8 (GND), U2.29_9 (GND), U3.13 (GND), U4.1 (CTG), U4.4 (GND), U4.6 (QSTRT), U4.9 (EP), U5.2 (VSS)
GPIOB: R1.1, U2.10 (IO8)
I2C_PW: U2.17 (IO19)
INT_RTC: R1_PINH1.1, TP15.TP, U2.8 (IO0), U3.3 (SQW/!INT)
IO/BOOT: BOOT_BUTTON.3, BOOT_BUTTON.4, C6.1, R_BOOT.1, U2.15 (IO9)
IO/CHANGE: C10.1, CHANGE_BUTTON.3, CHANGE_BUTTON.4, R_CHANGE.1, U2.23 (IO15)
MISO: D12.2, J4.P7 (DAT0), MISO.TP, R8.1, U2.27 (IO2)
MOSI: D11.2, J1.14, J4.P3 (CMD), MOSI.TP, R7.1, U1.5 (DI(IO0)), U2.7 (IO7)
unnamed: J2.B5, R2-USB.1
unnamed: J2.A5, R2-USB1.2
unnamed: C1_BAT1.1, D2.1 (CATHODE), IC4.1 (VIN), IC4.3 (CE)
unnamed: R1_BAT.2, U5.1 (STAT)
unnamed: R2_BAT.2, U5.5 (PROG)
unnamed: C4.1, D3.2 (A), D4.1 (K)
unnamed: CHG_LED.C, R1_BAT.1
unnamed: EPD_C1.2, J1.4
unnamed: EPD_C2.2, J1.5
unnamed: EPD_C6.2, J1.18
unnamed: EPD_C7.2, J1.19
unnamed: C_DELAY.1, IC1.5 (CT)
unnamed: EPD_C8.2, J1.20
unnamed: EPD_C10.2, J1.22
unnamed: EPD_C12.2, J1.24
unnamed: D7.1 (CATHODE), R_CAPACITOR.1
PREVGH: D5.1 (K), EPD_C9.2, J1.21
PREVGL: D4.2 (A), EPD_C11.2, J1.23
RESE: J1.3, Q3.2 (S), R3.2
RESE': R2.2, R3.1, SJ1.2
RESET: C5.1, IC1.1 (VOUT), RESET_BUTTON.3, RESET_BUTTON.4, R_RESET.1, U2.3 (EN)
RTC_RST: U2.16 (IO18), U3.4 (!RST)
RX: RX.TP, U2.24 (RXD0/GPIO17)
SCK: D10.2, J1.13, J4.P5 (CLK), R6.1, SCK.TP, U1.6 (CLK), U2.6 (IO6)
SCL: J3.4, R2-PINH.1, SENSOR2.4 (SCK), U2.20 (IO22), U3.16 (SCL), U4.7 (SCL)
SDA: J3.3, R1_PINH.1, SENSOR2.3 (SDI), U2.19 (IO21), U3.15 (SDA), U4.8 (SDA)
SRC: C4.2, D5.2 (A), L1.1, Q3.3 (D)
SS_SD: D8.2, J4.P2 (CD/DAT3), R10.1, U2.4 (IO4)
TX: TX.TP, U2.25 (TXD0/GPIO16)
USB_D+: D1.1 (I/O1_1), U2.14 (IO13)
USB_D-: D1.3 (I/O2_1), U2.13 (IO12)
VBAT: C2_BAT.1, Q1.3 (D), U4.2 (CELL), U4.3 (VDD), U5.3 (VBAT), VBAT.TP
VBUS: C1_BAT.1, C4_USB.1, C5_USB.1, CHG_LED.A, D1.5 (VBUS), D2.2 (ANODE), PFMF.050.1.2, Q1.1 (G), R1_PWRUSB.2, TP14.TP, U5.4 (VIN)
VRTC: C8.1, C10_SUPERCAP.1, R_CAPACITOR.2, U3.14 (VBAT)
VUSB: J2.A4, J2.A9, J2.B4, J2.B9, PFMF.050.1.1

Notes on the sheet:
DMG2305UX-7
BME688
SCHEMATIC
drawn by: CatalinaBuduran
USB C connector & ESD protection
LDO Voltage Regulator
SD Card
Display Type Selector
E-Paper Drive Circuit
Li-Po Battery Charging Controller
ESP32 C6
E-Paper Display Header
EPD Power
Environmental Sensor BME688
Voltage Supervisor + Reset & Boot/ IO Button
Battery Charge Level
RTC Module DS3231SN
Test Pads
Qwiic / Stemma QT
SPI ESD Protection Lines
External NOR Flash 64MB
SD0805S020S1R0

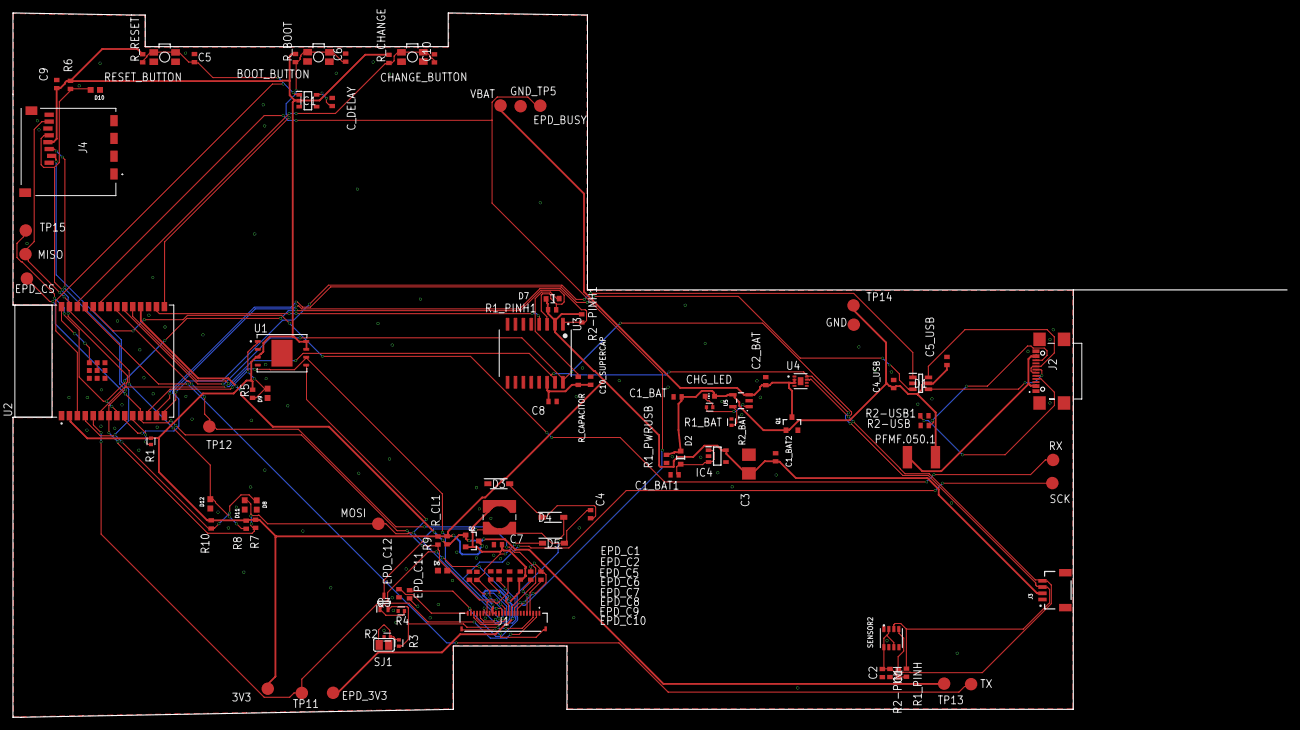
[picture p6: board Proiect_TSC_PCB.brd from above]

Board: 2 copper layers, 170.2 x 113.0 mm, 103 parts (0 on the bottom side), 55 nets.

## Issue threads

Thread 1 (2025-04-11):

[SCHEMATIC] - Consistency not checked Errors

dennisdobra, 2025-04-11:
Ai erori de tipul: SUPPLY pin <nume_pin> overwritten with more than one signal (ex: GND, N$8, N$5, N$10), ceea ce inseamna ca ai conectat anumiti pini la mai multe semnale diferite

Closed 2025-04-14.

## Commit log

2025-04-06 Add files via upload
    Schema+PCB
    [Proiect_TSC_PCB.brd, Proiect_TSC_schema.sch]
2025-04-06 Add files via upload
    Gerbers+BOM+PAP
    [PnP_Proiect_TSC_front_PickAndPlace.csv, Proiect_TSC_BOM.csv]
2025-04-15 Update schematic and PCB
    [Proiect_TSC_PCB.brd, Proiect_TSC_schema.sch]

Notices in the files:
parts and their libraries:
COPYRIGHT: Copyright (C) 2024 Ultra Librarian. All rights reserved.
